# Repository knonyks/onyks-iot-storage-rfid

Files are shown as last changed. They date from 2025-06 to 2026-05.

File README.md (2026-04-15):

# ONYX Projekt IoT skaner RFID do ewidencji

Skaner RFID do sprawdzania które narzędzia są obecnie w pracowni. Oparty o mikrokontroler [ESP32WROOM-32D](https://www.espressif.com/sites/default/files/documentation/esp32-wroom-32d_esp32-wroom-32u_datasheet_en.pdf) komunikujący się z zewnętrznym [modułem i anteną](https://pl.aliexpress.com/item/32907646941.html). W Polsce dozwolonym pasmem dla tego typu urządzeń jest UHF ok. 865-868 MHz oraz moc 2W EPR, co stanowi 33 dBm. Wybrany moduł emituje 26 dBm mocy, co w połączeniu z anteną … dBi (… dBd) mieści się w przepisowych ograniczeniach.  

Kod obsługujący moduł RFID i jego dokumentacja zostały zaczerpnięte z [repozytorium](https://github.com/playfultechnology/arduino-rfid-R200.git) użytkownika alastaira.

## Diagram blokowy urządzenia

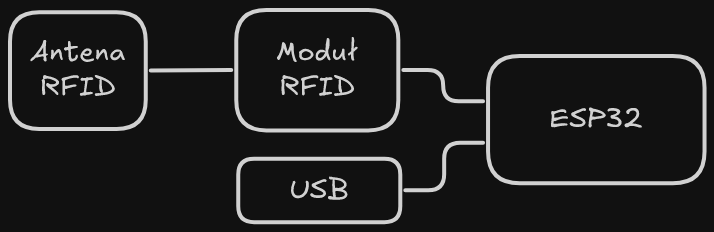
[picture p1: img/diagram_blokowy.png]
Diagram blokowy


## Schemat elektryczny układu

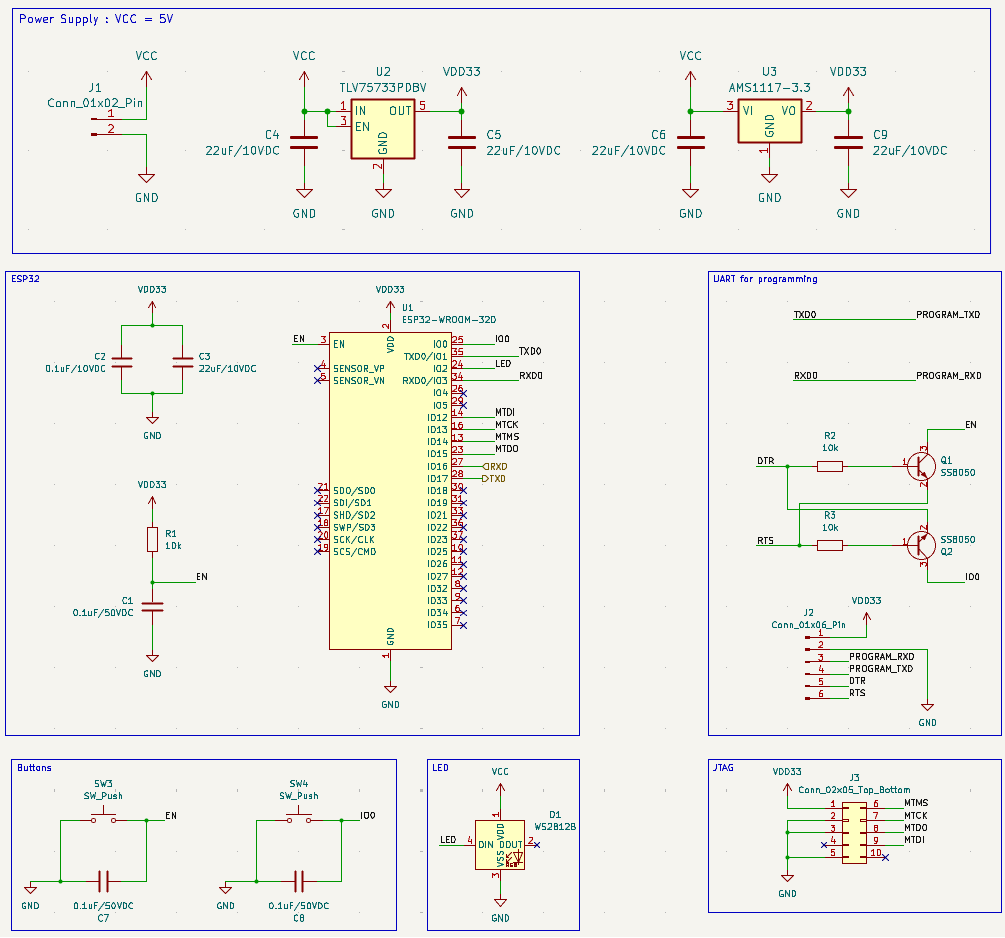
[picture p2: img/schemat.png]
Schemat Schemat układu


Płytka przyjmuje na wejście (Connector J1) napięcie 5V, które niestety jest przekazywane do modułu RFID bez stabilizacji, zatem powinno być napięciem stabilnym.

## Projekt płytki PCB

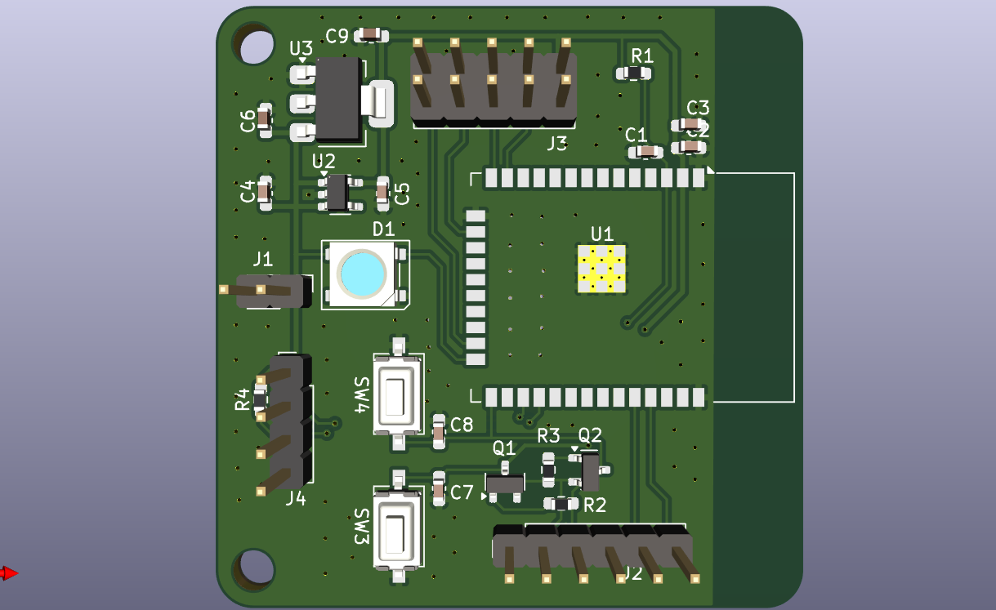
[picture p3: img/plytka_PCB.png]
Plytka PCB Projekt płytki PCB


|Connector name|Pin|Przeznaczenie|
|-|-|-|
|J1 - power supply|1|GND|
|J1 - power supply|2|5V|
|J2 - UART for programming|1|GND|
|J2 - UART for programming|2|RTS|
|J2 - UART for programming|3|DTR|
|J2 - UART for programming|4|3V3|
|J2 - UART for programming|5|RXD|
|J2 - UART for programming|6|TXD|
|J3 - JTAG|1x1|GND|
|J3 - JTAG|1x2|NC|
|J3 - JTAG|1x3|GND|
|J3 - JTAG|1x4|GND|
|J3 - JTAG|1x5|3V3|
|J3 - JTAG|2x1|MTDO|
|J3 - JTAG|2x2|MTCK|
|J3 - JTAG|2x3|MTDI|
|J3 - JTAG|2x4|MTMS|
|J3 - JTAG|2x5|NC|
|J4 - moduł RFID|1|5V|
|J4 - moduł RFID|2|RXD|
|J4 - moduł RFID|3|TXD|
|J4 - moduł RFID|4|GND|

Numeracja pinów w tabeli odnosi się do powyższego zdjęcia płytki PCB od lewej strony każdego connectora, z wyjątkiem J4, gdzie kolejność jest od góry.

## Lista elementów

Interaktywna lista elementów znajduje się w pliku ./pcb/BOM.html.

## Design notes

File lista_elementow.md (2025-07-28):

# Lista elementów zewnętrznych

| **Nazwa** | **Info** | **Specyfikacje (linki)** | **Sklep (link)** | 
| -- | -- | -- | -- |
| ESP32WROOM-32D | Napięcie: 3V/3.6V | - https://www.espressif.com/sites/default/files/documentation/esp32-wroom-32d_esp32-wroom-32u_datasheet_en.pdf | https://kamami.pl/esp32/1179653-modul-esp32-wroom-32d-32mbit-4mb-5906623442843.html |
| R200 Chip (z anteną) | Napięcie: 3.3V/5V</br> Zasięg: 5m | - https://deepwiki.com/playfultechnology/arduino-rfid-R200/1-overview </br> - https://github.com/playfultechnology/arduino-rfid-R200 | https://pl.aliexpress.com/item/32907646941.html |

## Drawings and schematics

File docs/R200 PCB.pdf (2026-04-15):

# U6U⁶x1

# U13U¹³x1

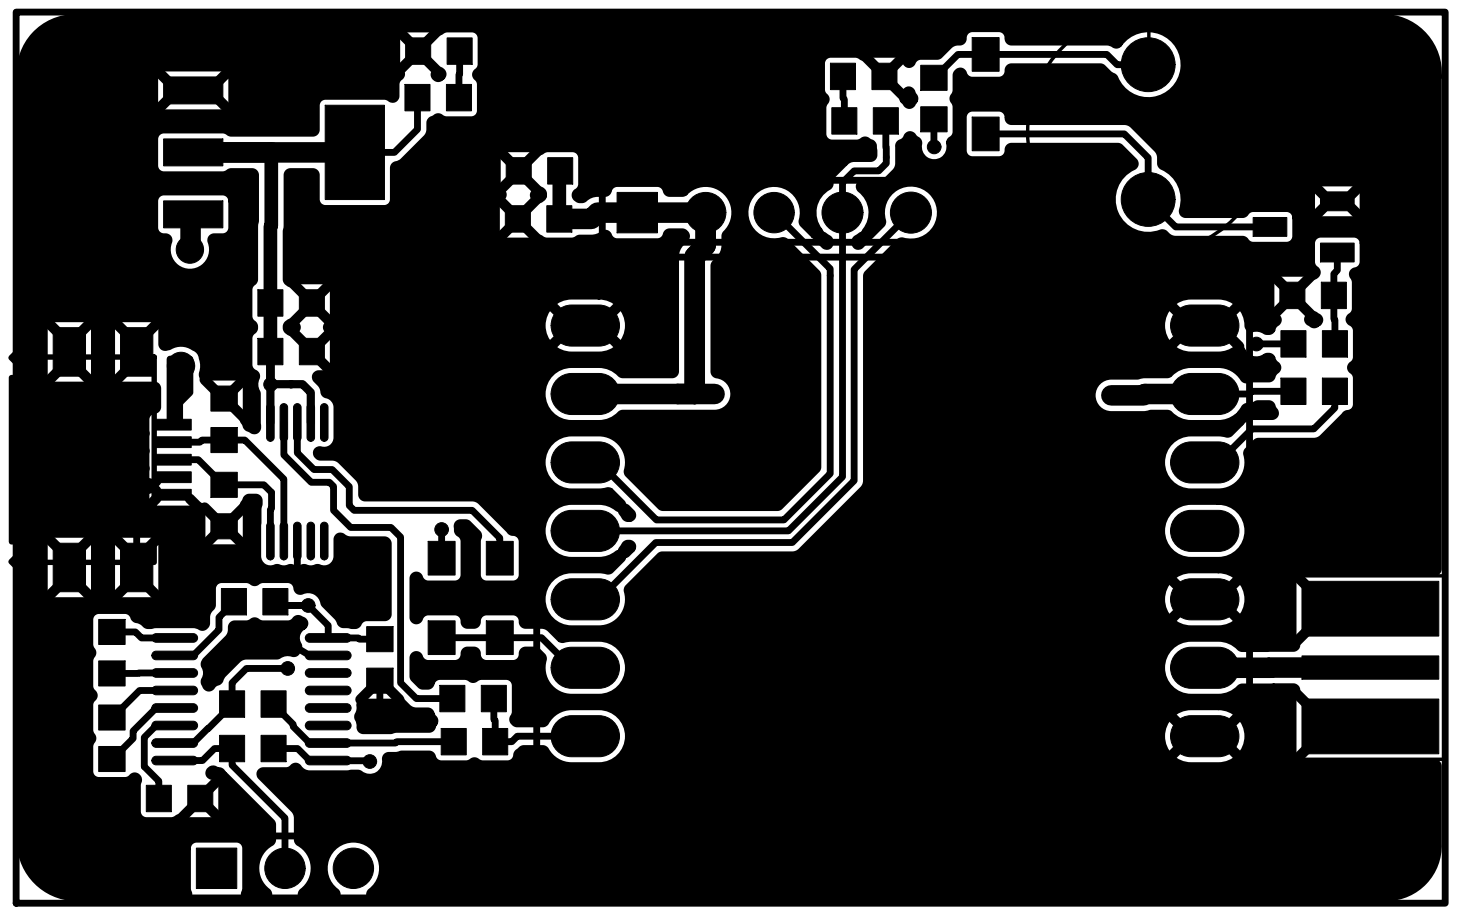
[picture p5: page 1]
CON1CON¹x1 CON¹x4 CON¹x5; C6C⁶x1; C⁶x2; R4R⁴x2; R⁴x1; R12R¹²x2; R¹²x1; R11R¹¹x1; R¹¹x2; Q1Q¹x1 Q¹x2 Q¹x3; R10R¹⁰x2; R¹⁰x1; D6D⁶x2; D⁶x1; R9R⁹x1 R⁹x2; D5D⁵x1 D⁵x2; SPEAKER1 SPEAKER¹x1 SPEAKER¹x2; C8C⁸x1; C⁸x2; C7C⁷x1 C⁷x2; C9C⁹x1; C⁹x2; U2U²x1 U²x2 U²x3 U²x4 U²x5 U²x10 U²x9 U²x8 U²x7 U²x6; C10C¹⁰x1 C¹⁰x2; U14U¹⁴x1; C11C¹¹x1 C¹¹x2; C2C²x2; C²x1; C3C³x2; C³x1; C5C⁵x1; C⁵x2; D1D¹x1 D¹x2; D2D²x1; D²x2; D3D³x1; R1R¹x1; R¹x2; R13R¹³x1; R¹³x2; R14R¹⁴x1; R¹⁴x2; R15R¹⁵x2; R¹⁵x1; U1U¹x1 U¹x2; U¹x2/2 U¹x3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

# RP20 RP26

# D6R9D5

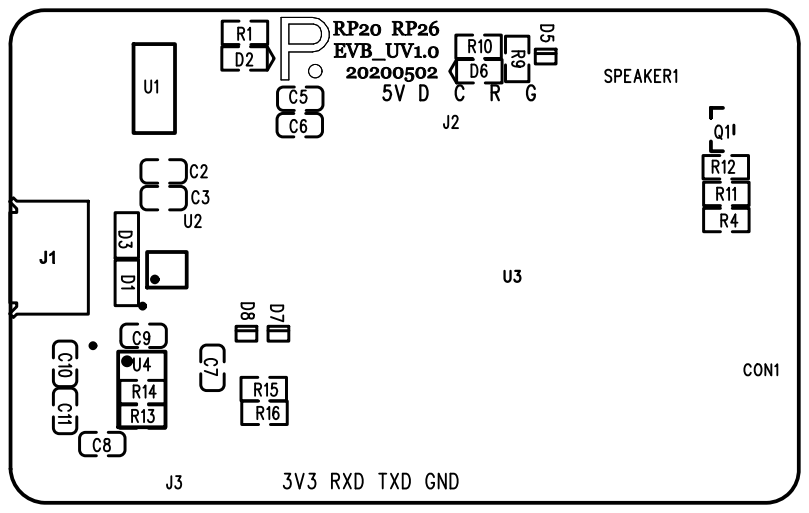
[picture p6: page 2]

# U13U¹³x1

# U6U⁶x1

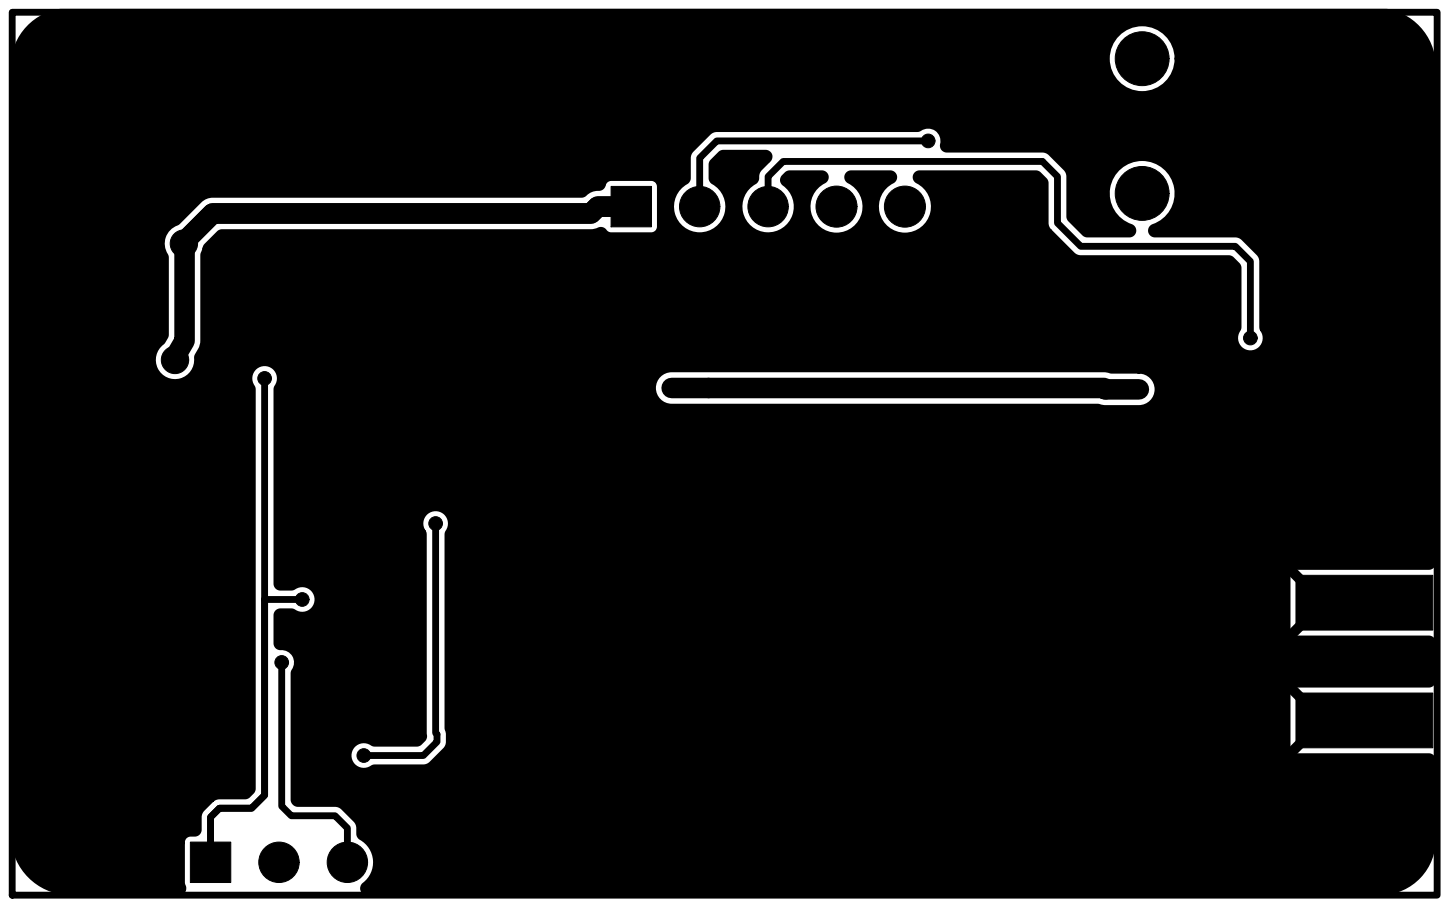
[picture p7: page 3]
CON1CON¹x2 CON¹x3; SPEAKER1 SPEAKER¹x1 SPEAKER¹x2; U14U¹⁴x1; U5U⁵x1

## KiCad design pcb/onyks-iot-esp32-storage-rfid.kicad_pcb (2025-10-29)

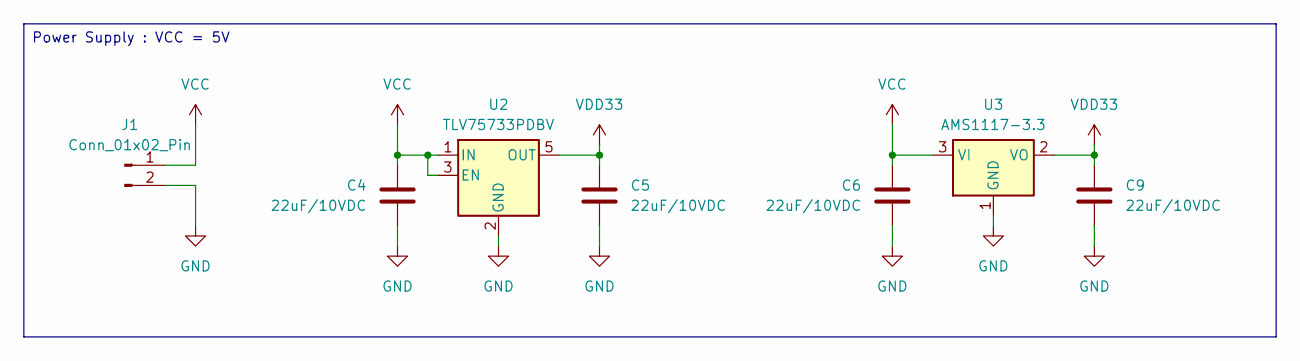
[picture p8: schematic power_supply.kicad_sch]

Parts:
C4, C5, C6, C9: 22uF/10VDC; C_0603_1608Metric_Pad1.08x0.95mm_HandSolder
J1: Conn_01x02_Pin; PinHeader_1x02_P2.54mm_Vertical
U2: TLV75733PDBV; SOT-23-5
U3: AMS1117-3.3; SOT-223-3_TabPin2

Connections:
GND: C4.2, C5.2, C6.2, C9.2, J1.2, U2.2 (GND), U3.1 (GND); also elsewhere on the board
VCC: C4.1, C6.1, J1.1, U2.1 (IN), U2.3 (EN), U3.3 (VI); also elsewhere on the board
VDD33: C5.1, C9.1, U2.5 (OUT), U3.2 (VO); also elsewhere on the board

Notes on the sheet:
Power Supply : VCC = 5V

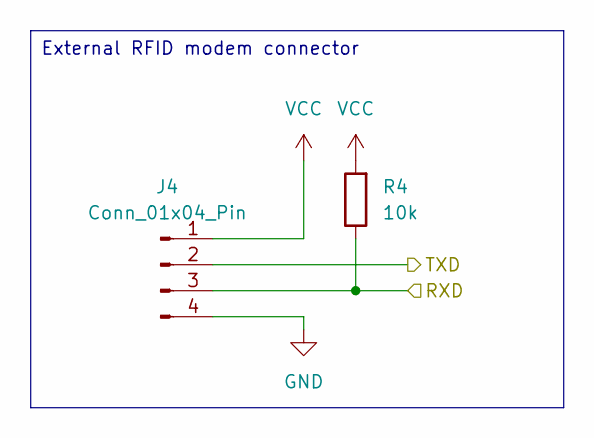
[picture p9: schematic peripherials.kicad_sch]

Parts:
J4: Conn_01x04_Pin; PinHeader_1x04_P2.54mm_Vertical
R4: 10k; R_0603_1608Metric_Pad0.98x0.95mm_HandSolder

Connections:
/ESP32/RXD: J4.2; also elsewhere on the board
/ESP32/TXD: J4.3, R4.1; also elsewhere on the board
GND: J4.4; also elsewhere on the board
VCC: J4.1, R4.2; also elsewhere on the board

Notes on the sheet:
External RFID modem connector

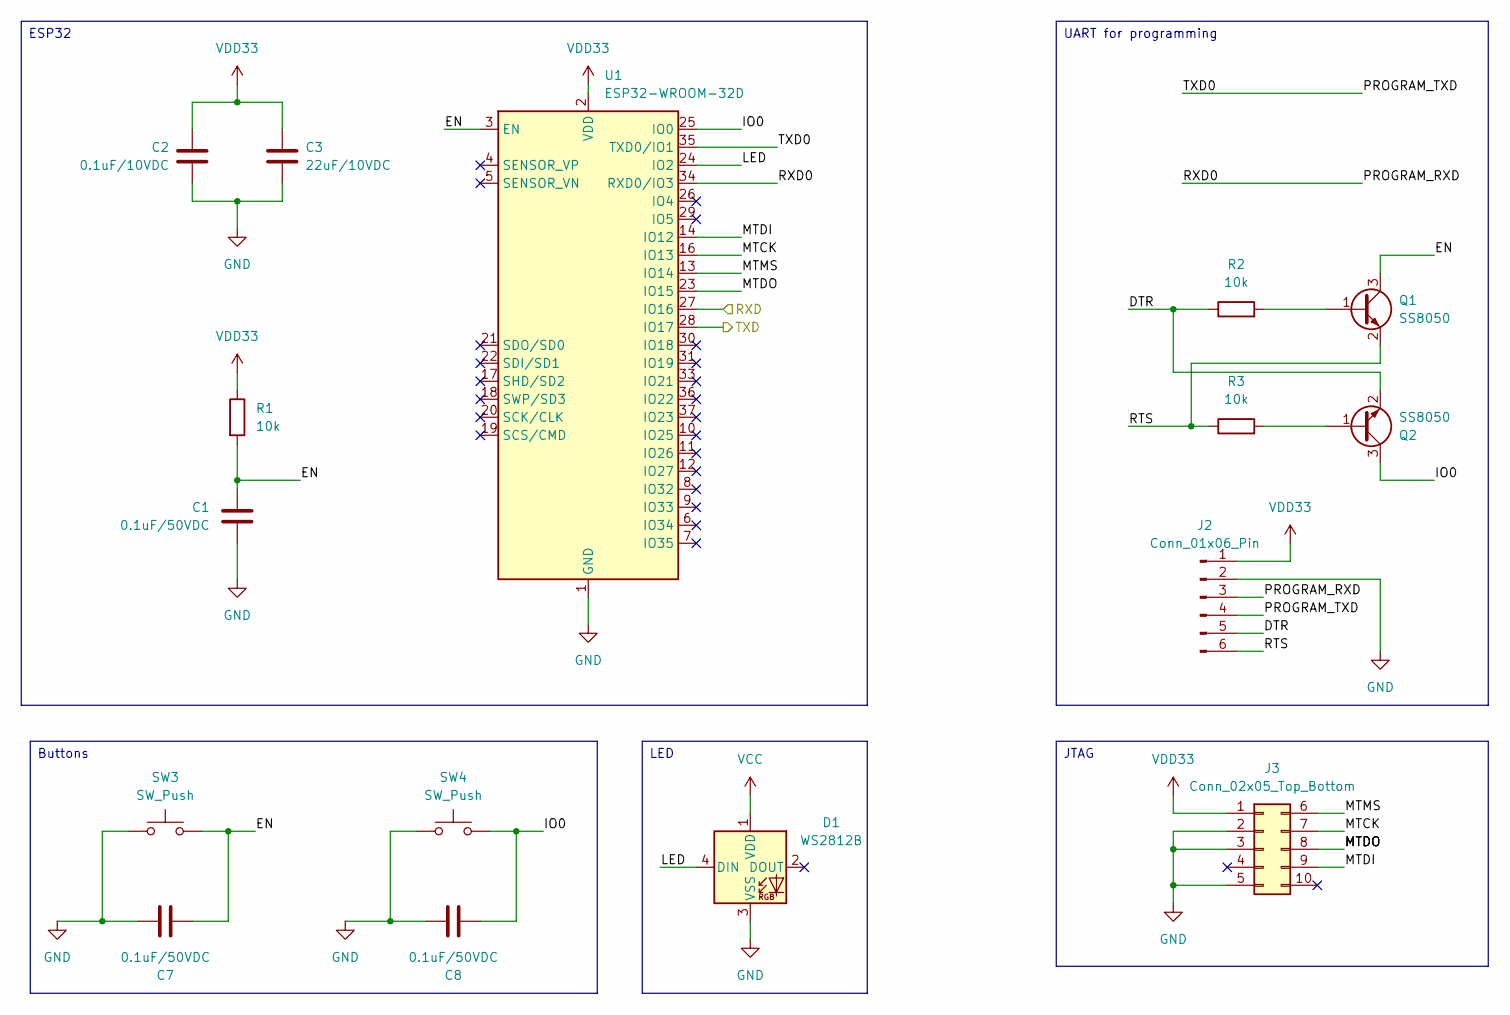
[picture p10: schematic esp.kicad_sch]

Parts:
C1, C7, C8: 0.1uF/50VDC; C_0603_1608Metric_Pad1.08x0.95mm_HandSolder
C2: 0.1uF/10VDC; C_0603_1608Metric_Pad1.08x0.95mm_HandSolder
C3: 22uF/10VDC; C_0603_1608Metric_Pad1.08x0.95mm_HandSolder
D1: WS2812B; LED_WS2812B_PLCC4_5.0x5.0mm_P3.2mm
J2: Conn_01x06_Pin; PinHeader_1x06_P2.54mm_Vertical
J3: Conn_02x05_Top_Bottom; PinHeader_2x05_P2.54mm_Vertical
Q1, Q2: SS8050; SOT-23
R1, R2, R3: 10k; R_0603_1608Metric_Pad0.98x0.95mm_HandSolder
SW3, SW4: SW_Push; SW_Tactile_SPST_NO_Straight_CK_PTS636Sx25SMTRLFS
U1: ESP32-WROOM-32D

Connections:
/ESP32/DTR: J2.5, Q2.2 (E), R2.1
/ESP32/EN: C1.2, C7.2, Q1.3 (C), R1.2, SW3.2, U1.3 (EN)
/ESP32/IO0: C8.2, Q2.3 (C), SW4.2, U1.25 (IO0)
/ESP32/LED: D1.4 (DIN), U1.24 (IO2)
/ESP32/MTCK: J3.7, U1.16 (IO13)
/ESP32/MTDI: J3.9, U1.14 (IO12)
/ESP32/MTDO: J3.8, U1.23 (IO15)
/ESP32/MTMS: J3.6, U1.13 (IO14)
/ESP32/PROGRAM_RXD: J2.3, U1.34 (RXD0/IO3)
/ESP32/PROGRAM_TXD: J2.4, U1.35 (TXD0/IO1)
/ESP32/RTS: J2.6, Q1.2 (E), R3.1
/ESP32/RXD: U1.27 (IO16); also elsewhere on the board
/ESP32/TXD: U1.28 (IO17); also elsewhere on the board
GND: C1.1, C2.2, C3.2, C7.1, C8.1, D1.3 (VSS), J2.2, J3.2, J3.3, J3.5, SW3.1, SW4.1, U1.1 (GND), U1.15 (GND), U1.38 (GND), U1.39 (GND); also elsewhere on the board
unnamed: Q1.1 (B), R2.2
unnamed: Q2.1 (B), R3.2
VCC: D1.1 (VDD); also elsewhere on the board
VDD33: C2.1, C3.1, J2.1, J3.1, R1.1, U1.2 (VDD); also elsewhere on the board

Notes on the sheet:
LED
UART for programming
Buttons
JTAG
ESP32

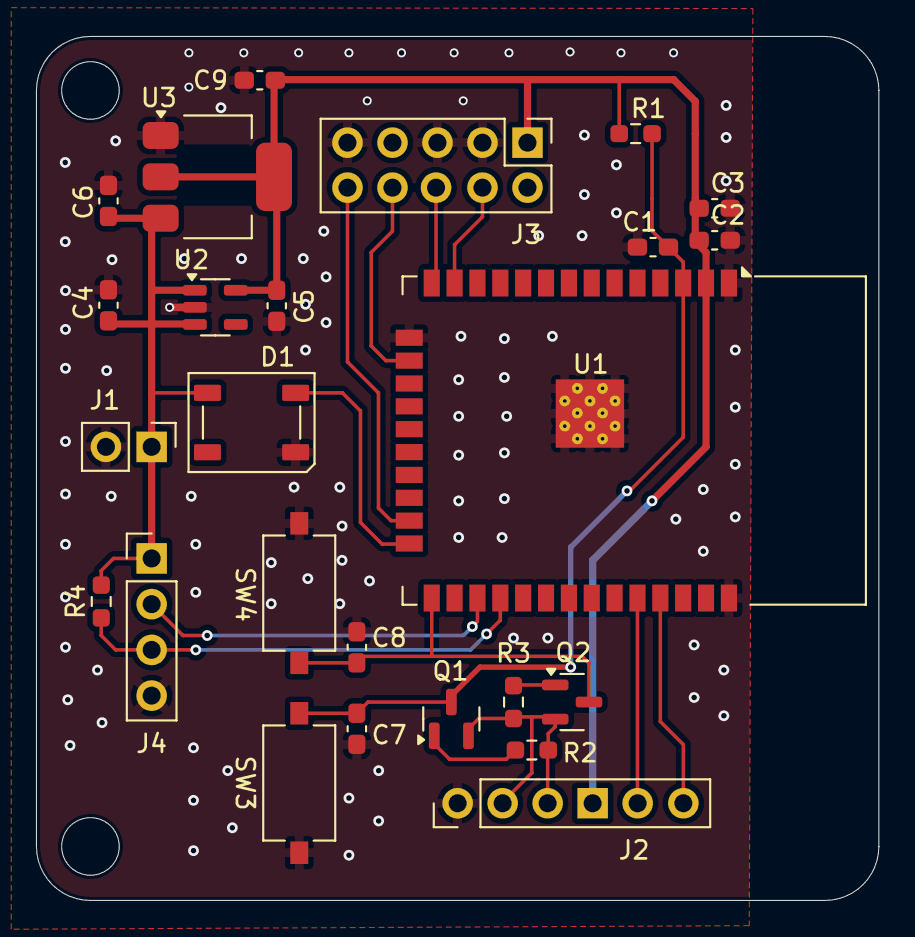
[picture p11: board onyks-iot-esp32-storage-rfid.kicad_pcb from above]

Board: 4 copper layers, 46.8 x 48.0 mm, 25 parts (0 on the bottom side), 18 nets.

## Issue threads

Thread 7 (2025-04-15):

Lista "TODO" etapów projektu

Xenon02, 2025-04-15:
### Wstępne działania projektowe

- [ ] Wykonanie schematu blokowego urządzenia (w README lub w oddzielnym pliku tekstowym/graficznym)
- [ ] Dobranie elementów i sporządzenie listy elementów w Excelu
- [ ] Poddanie tego schematu blokowego do weryfikacji (oznaczenie w issue) @przemech i/lub @Xenon02

### Sporządzenie układu elektronicznego

- [ ] [Hierarchiczna struktura schematu](https://docs.kicad.org/master/en/eeschema/eeschema.html#hierarchical-schematics)
- [ ] Global Label -> Net Label (lokalne)
- [ ] Global Label -> Hierarchical Label (między schematami)
- [ ] No Connect Flags dla niepodłączoncych pinów
- [ ] Czytanie schematów od lewej do prawej -> np. zasilanie po lewej i odbiorca po prawej
- [ ] Zbyt dokładne wartości elementów (zbyt dokładny szereg)
- [ ] Nazwa modelu cewki do symbolu  jako kolejny field
- [ ] Napięcia przy kondensatorach np. 10u -> 10n/10V
- [ ] Obudowy SMD 0603 (ew. dla kondesnatorów o dużych pojemnościach 0805)
- [ ] Przy złączu zasilania opis zakresu napięcia i maksymalny prąd

-[ ] Poddanie tego schematu elektronicznego do weryfikacji (oznaczenie w issue) @przemech

### Lista do wykonania płytki PCB będzie później wykonana i zaktualizowana. W razie wcześniejszego działania zapraszam do obejrzenia : (https://www.youtube.com/watch?v=UhMvmdq2B5E)

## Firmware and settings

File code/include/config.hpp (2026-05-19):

#pragma once

#include <cstdint>
#include <vector>

#include "freertos/FreeRTOS.h"
#include "freertos/task.h"
#include "freertos/queue.h"
#include "driver/uart.h"
#include "esp_log.h"

#define LED_PIN                 2

#define R200_UART               UART_NUM_2
#define R200_BAUD               115200
#define R200_RX_PIN             16
#define R200_TX_PIN             17
#define R200_RX_BUFF_SIZE       512
#define R200_TX_BUFF_SIZE       0

#define WIFI_EVENT_QUEUE_SIZE   8
#define CMD_EVENT_QUEUE_SIZE    8
#define UART_EVENT_QUEUE_SIZE   24
#define DATA_EVENT_QUEUE_SIZE   24

#define TAG_LED                 "WS2812B"
#define TAG_R200                "R200"

enum rfid_event_type_t : uint8_t {
    IDLE_STATUS = 0x00, 
    TAG_READ = 0x01,
    ERROR_INFO = 0x02
};

struct rfid_event_t {
    rfid_event_type_t type;
    uint8_t rssi;
    uint8_t data[24];
    uint8_t data_len;
};

struct ha_event_t {
    uint8_t cmd;
    uint8_t params[16];
    uint8_t param_len;
};

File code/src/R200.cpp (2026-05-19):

#include "R200.hpp"

void R200::init() {
    // send_cmd(R200_Command::SetWorkArea, {0x03}); // Set work area to EU3 (865-868MHz)
    // send_cmd(R200_Command::SetTransmitPower, {0x0A, 0x28}); // Set transmit power to 26 dBm (0x0A28 = 0d2600 dBm)
    // send_cmd(R200_Command::SetQueryParameters, {0x11, 0x20});

    ESP_LOGI(TAG_R200, "R200 initialized on UART%d", R200_UART);
}

esp_err_t R200::send_cmd(const ha_event_t& event) {
    uint8_t cmd = event.cmd;
    uint16_t param_len = event.param_len;

    // Header, Type, Command, ParamLen(2), Params, Checksum, End
    std::vector<uint8_t> frame(5 + param_len + 2);

    frame.at(R200_FrameStructure::HeaderPos) = R200_FrameControl::Header;
    frame.at(R200_FrameStructure::TypePos) = R200_FrameType::Command;
    frame.at(R200_FrameStructure::CommandPos) = cmd;
    frame.at(R200_FrameStructure::ParamLengthMSBPos) = (param_len >> 8) & 0xFF; // ParamLen MSB
    frame.at(R200_FrameStructure::ParamLengthLSBPos) = param_len & 0xFF;        // ParamLen LSB
    for (size_t i = 0; i < param_len; ++i)
        frame.at(R200_FrameStructure::ParamPos + i) = event.params[i];
    frame.at(R200_FrameStructure::ParamPos + param_len) = check_frame(frame, param_len);
    frame.at(R200_FrameStructure::ParamPos + param_len + 1) = R200_FrameControl::End;

    if (uart_write_bytes(R200_UART, frame.data(), sizeof(frame)) < 0) {
        ESP_LOGE(TAG_R200, "Failed to send command 0x%02X", cmd);
        return ESP_FAIL;
    }

    ESP_LOGI(TAG_R200, "Command 0x%02X sent with %d params", cmd, param_len);
    return ESP_OK;
}

esp_err_t R200::receive_data() {
    uint8_t header, type, cmd, sum, end;
    uint16_t param_len;
    std::vector<uint8_t> frame{};

    // reading the first 5 bytes of the frame: Header, Type, Command, ParamLen(2)
    if (uart_read_bytes(R200_UART, frame.data(), 5, pdMS_TO_TICKS(20)) != 5) {
        uart_flush_input(R200_UART);
        ESP_LOGE(TAG_R200, "Unable to read frame's header bytes");
        return ESP_FAIL;
    }

    header = frame.at(R200_FrameStructure::HeaderPos);
    type = frame.at(R200_FrameStructure::TypePos);
    cmd = frame.at(R200_FrameStructure::CommandPos);
    param_len = frame.at(R200_FrameStructure::ParamLengthMSBPos) << 8;
    param_len |= frame.at(R200_FrameStructure::ParamLengthLSBPos);

    if (header != R200_FrameControl::Header) {
        uart_flush_input(R200_UART);
        return ESP_FAIL;
    }

    frame.resize(5 + param_len + 2);
    uart_read_bytes(R200_UART, frame.data() + R200::R200_FrameStructure::ParamPos, param_len + 2, pdMS_TO_TICKS(40));

    sum = frame.at(R200_FrameStructure::ParamPos + param_len);
    end = frame.at(R200_FrameStructure::ParamPos + param_len + 1);

    if (sum != check_frame(frame, param_len)) {
        uart_flush_input(R200_UART);
        ESP_LOGE(TAG_R200, "Invalid frame checksum");
        return ESP_FAIL;
    }

    if (end != R200_FrameControl::End) {
        uart_flush_input(R200_UART);
        return ESP_FAIL;
    }

    //process_frame(type, cmd, fra.data(), param_len);

    return ESP_OK;
}

uint8_t R200::check_frame(const std::vector<uint8_t>& frame, uint16_t param_len) {
    uint8_t checkSum = 0; // we only take the LSB of the sum
    
    // check sum does not include the header and end byte
    for (size_t i = 1; i < R200_FrameStructure::ParamPos + param_len; ++i)
        checkSum += frame.at(i);

    return checkSum;
}

// void printHexByte(char* name, uint8_t value){
//   Serial.print(name);
//   Serial.print(":");
//   Serial.print(value < 0x10 ? "0x0" : "0x");
//   Serial.println(value, HEX);
// }

// void printHexBytes(char* name, uint8_t *value, uint8_t len){
//   Serial.print(name);
//   Serial.print(":");
//   Serial.print("0x");
//   for(int i=0; i<len; i++){
//     Serial.print(value[i] < 0x10 ? "0" : "");
//     Serial.print(value[i], HEX);
//   }
//   Serial.println("");
// }

// void printHexWord(char* name, uint8_t MSB, uint8_t LSB){
//   Serial.print(name);
//   Serial.print(":");
//   Serial.print(MSB < 0x10 ? "0x0" : "0x");
//   Serial.println(MSB, HEX);
//   Serial.print(LSB < 0x10 ? "0" : "");
//   Serial.println(LSB, HEX);
// }
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

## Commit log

2025-07-28 Nie pełna lista elementów wykorzystywanych w projekcie. Zrobiony schemat (bez rewizii).
    [esp.kicad_sch, onyks-iot-esp32-storage-rfid.kicad_pcb, onyks-iot-esp32-storage-rfid.kicad_sch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]
2025-07-28 Zapomniałem o rulesach.
    [onyks-iot-esp32-storage-rfid.kicad_pcb]
2025-08-20 oznaczenie pinów i podział elementów PCB
    dodanie oznaczenia nieużywanych pinów zgodnie z opinią schematu
    [esp.kicad_sch, onyks-iot-esp32-storage-rfid.kicad_pcb, onyks-iot-esp32-storage-rfid.kicad_sch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]
2025-08-23 ustawienie i połączenia na PCB
    szerokości ścieżek i wielkości przelotek jeszcze do poprawy
    [onyks-iot-esp32-storage-rfid.kicad_pcb]
2025-08-31 szerokości ścieżek
    [onyks-iot-esp32-storage-rfid.kicad_pcb]
2025-09-09 PCB gotowe do review
    [onyks-iot-esp32-storage-rfid.kicad_pcb]
2025-10-22 projekt PCB v2
    [onyks-iot-esp32-storage-rfid.kicad_pcb, peripherials.kicad_sch]
2025-10-23 projekt PCB v2.2
    Projekt gotowy do review. @przemech @Xenon02
    Dodany zostal drugi stabilizator AMS1117-3.3, ktory mamy w nadmiarze w kole.
    Zaktualizowano DR na zgodne z JLCPCB capabilities, ktore wczesniej byly bledne.
    Dodano opis wymiarow plytki.
    [onyks-iot-esp32-storage-rfid.kicad_pcb, power_supply.kicad_sch]
2025-10-23 zrobione review, wprowadzone poprawki, czeka na ostatnie sprawdzenie jak prezes bedzie bardizej przytomny
    [esp.kicad_sch, onyks-iot-esp32-storage-rfid.kicad_pcb]
2025-10-26 Adding Gerber files
    [onyks-iot-esp32-storage-rfid-B_Cu.gbr, onyks-iot-esp32-storage-rfid-B_Mask.gbr, onyks-iot-esp32-storage-rfid-B_Paste.gbr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]
2025-10-29 male zmiany PCB
    poprawiono niezmienione przelotki i usunieto powierzchnie masy pod U3
    [onyks-iot-esp32-storage-rfid.kicad_pcb]
2025-11-16 Aktualizacja gerberów, powiązane z dwoma poprzednimi commit-ami
    [onyks-iot-esp32-storage-rfid-B_Cu.gbr, onyks-iot-esp32-storage-rfid-B_Mask.gbr, onyks-iot-esp32-storage-rfid-B_Paste.gbr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]
2025-11-16 Poprawka folderu gdzie gerbery zostały włożone (/pcb/onyks-iot-esp32-storage-rfid/Fabrication a powinno być /Fabrication)
    [onyks-iot-esp32-storage-rfid-B_Cu.gbr, onyks-iot-esp32-storage-rfid-B_Mask.gbr, onyks-iot-esp32-storage-rfid-B_Paste.gbr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]
2026-03-23 dokumentacja plytki v1.0
    [onyks-iot-esp32-storage-rfid-B_Cu.gbr, onyks-iot-esp32-storage-rfid-B_Mask.gbr, onyks-iot-esp32-storage-rfid-B_Paste.gbr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]
2026-03-23 dokumentacja v1.1
    dodanie zdjęcia płytki PCB i poprawa adresacji pliku BOM.html
2026-04-15 kod ESP32 v0.0
    program przykładowy, test działania układu
2026-04-16 dokumentacja v1.2
    porządek w plikach i datasheet ESP32
    [esp.kicad_sch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]
2026-05-06 kod ESP32 v0.1
    konfiguracja diody i uart dla R200
2026-05-09 kod ESP32 v0.2
    klasa UART i funkcja wysylajaca ramki do R200
2026-05-19 kod ESP32 v0.3
    zmiany w klasie R200, funkcje wysyłające i odbierające ramki do R200, obsługa tasków w freeRTOS
